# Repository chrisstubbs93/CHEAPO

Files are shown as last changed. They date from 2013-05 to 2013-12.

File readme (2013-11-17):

Flight code for $$CHEAPO flight computer

Just a simple uBlox NEO 6 GPS / RFM22B tracker

Should be uploaded to "Arduino Pro or Pro Mini (3.3v, 8MHz) w/ ATmega328"

Main tracker code is CHEAPO.INO in root directory, other code in subfolders should be treated as experimental/untested.

Current hardware CHEAPOv4 http://chris-stubbs.co.uk/wp/?p=352

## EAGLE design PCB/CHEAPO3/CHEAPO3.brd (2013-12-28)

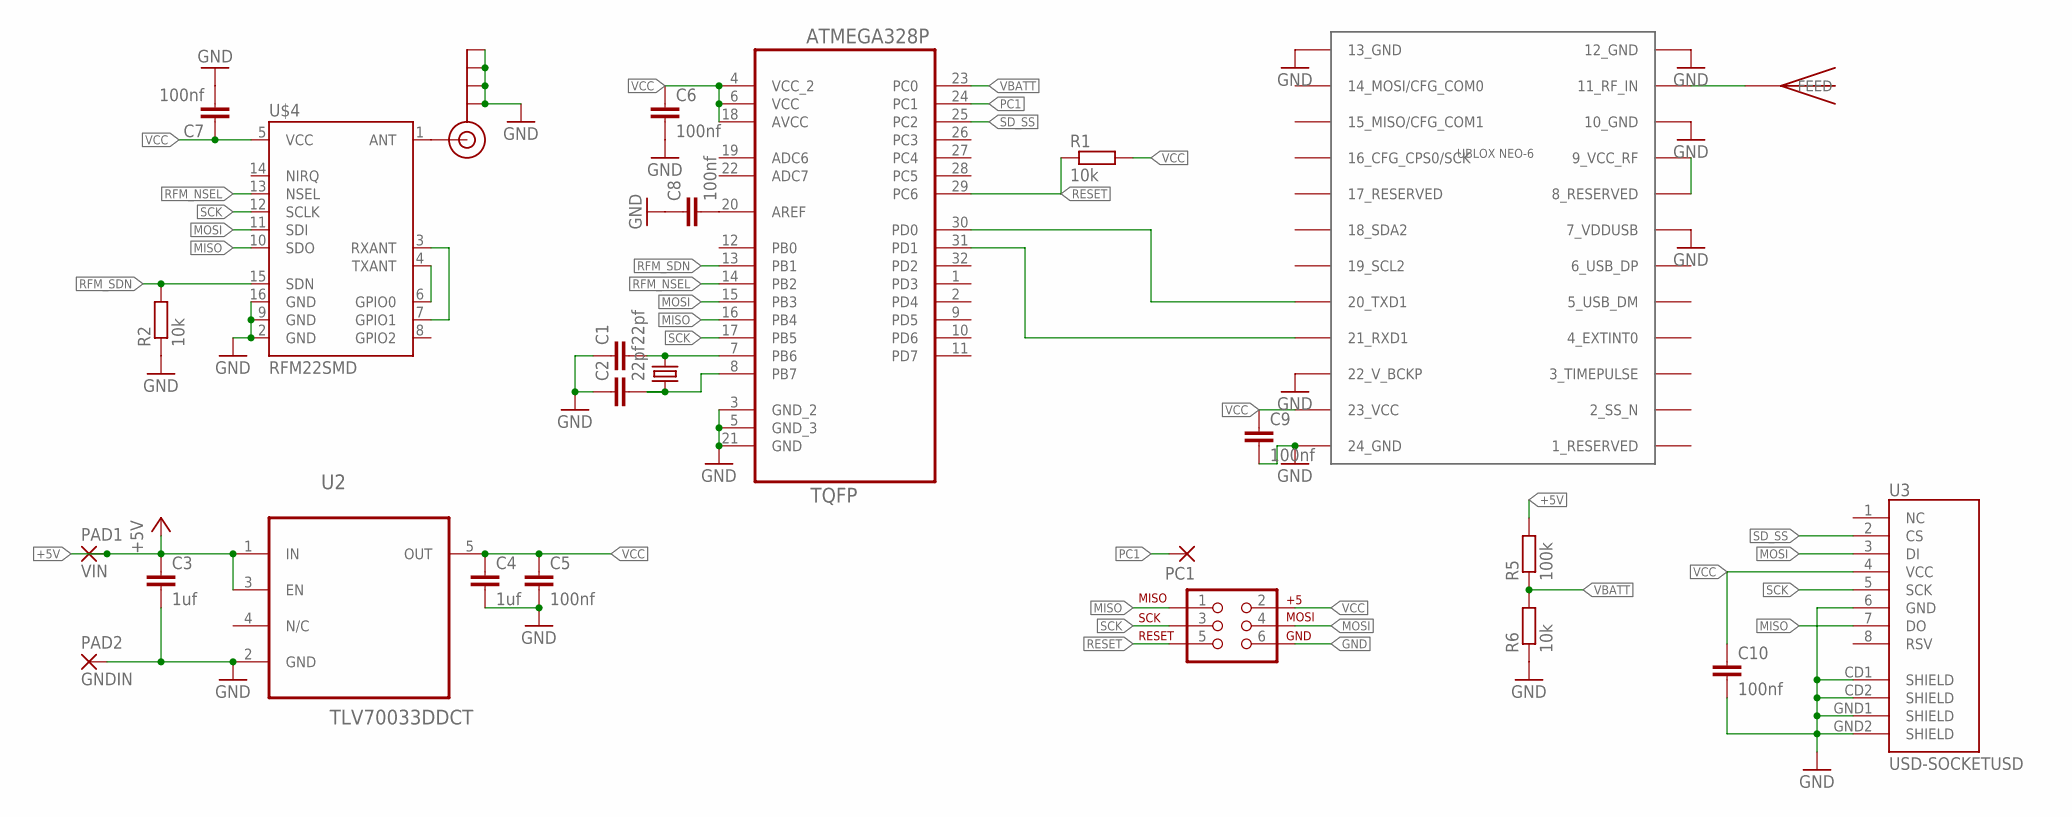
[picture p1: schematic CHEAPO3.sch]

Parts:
C1, C2: 22pf; C0603
C3, C4: 1uf; C0603
C5, C6, C7, C8, C9, C10: 100nf; C0603
J1: AVR_SPI_PRG_6PTH; 2X3
J$1: SMA_EDGE; SMA-EDGE
PAD1: VIN; SMD1,27-2,54
PAD2: GNDIN; SMD1,27-2,54
PC1: SMD2; SMD1,27-2,54
R1, R2, R6: 10k; R0603
R5: 100k; R0603
U1: ATMEGA328P-AU; QFP80P900X900X120-32N
U2: TLV70033DDCT; SOT95P280X110-5N
U3: USD-SOCKETUSD; USD-SOCKET-PP
U$1: UBLOX_NEO-6; UBLOX_NEO-6P
U$2: ABRACON_ABM3_CRYSTALABM03_HC49; ABM03_HC49
U$3: JTI_ANTENNA-1575AT43A40
U$4: RFM22SMD; RFM22-XXX-S2

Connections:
+5V: C3.1, PAD1.1, R5.2, U2.1 (IN), U2.3 (EN)
GND: C1.1, C2.1, C3.2, C4.2, C5.2, C6.2, C7.2, C8.1, C9.2, C10.2, J1.6, J$1.GND@0 (GND), J$1.GND@1 (GND), J$1.GND@2 (GND), J$1.GND@3 (GND), PAD2.1, R2.1, R6.1, U1.3 (GND_2), U1.5 (GND_3), U1.21 (GND), U2.2 (GND), U3.6 (GND), U3.CD1 (SHIELD), U3.CD2 (SHIELD), U3.GND1 (SHIELD), U3.GND2 (SHIELD), U$1.7_VDDUSB, U$1.10_GND, U$1.12_GND, U$1.13_GND, U$1.22_V_BCKP, U$1.24_GND, U$4.2 (GND), U$4.9 (GND), U$4.16 (GND)
MISO: J1.1, U1.16 (PB4), U3.7 (DO), U$4.10 (SDO)
MOSI: J1.4, U1.15 (PB3), U3.3 (DI), U$4.11 (SDI)
unnamed: C1.2, U1.7 (PB6), U$2.2
unnamed: C2.2, U1.8 (PB7), U$2.1
unnamed: U$4.4 (TXANT), U$4.6 (GPIO0)
unnamed: U$4.3 (RXANT), U$4.7 (GPIO1)
unnamed: U$1.8_RESERVED, U$1.9_VCC_RF
unnamed: U$1.11_RF_IN, U$3.FEED
unnamed: C8.2, U1.20 (AREF)
unnamed: J$1.SIG (SIGNAL), U$4.1 (ANT)
unnamed: U1.30 (PD0), U$1.20_TXD1
unnamed: U1.31 (PD1), U$1.21_RXD1
PC1: PC1.1, U1.24 (PC1)
RESET: J1.5, R1.1, U1.29 (PC6)
RFM_NSEL: U1.14 (PB2), U$4.13 (NSEL)
RFM_SDN: R2.2, U1.13 (PB1), U$4.15 (SDN)
SCK: J1.3, U1.17 (PB5), U3.5 (SCK), U$4.12 (SCLK)
SD_SS: U1.25 (PC2), U3.2 (CS)
VBATT: R5.1, R6.2, U1.23 (PC0)
VCC: C4.1, C5.1, C6.1, C7.1, C9.1, C10.1, J1.2, R1.2, U1.4 (VCC_2), U1.6 (VCC), U1.18 (AVCC), U2.5 (OUT), U3.4 (VCC), U$1.23_VCC, U$4.5 (VCC)

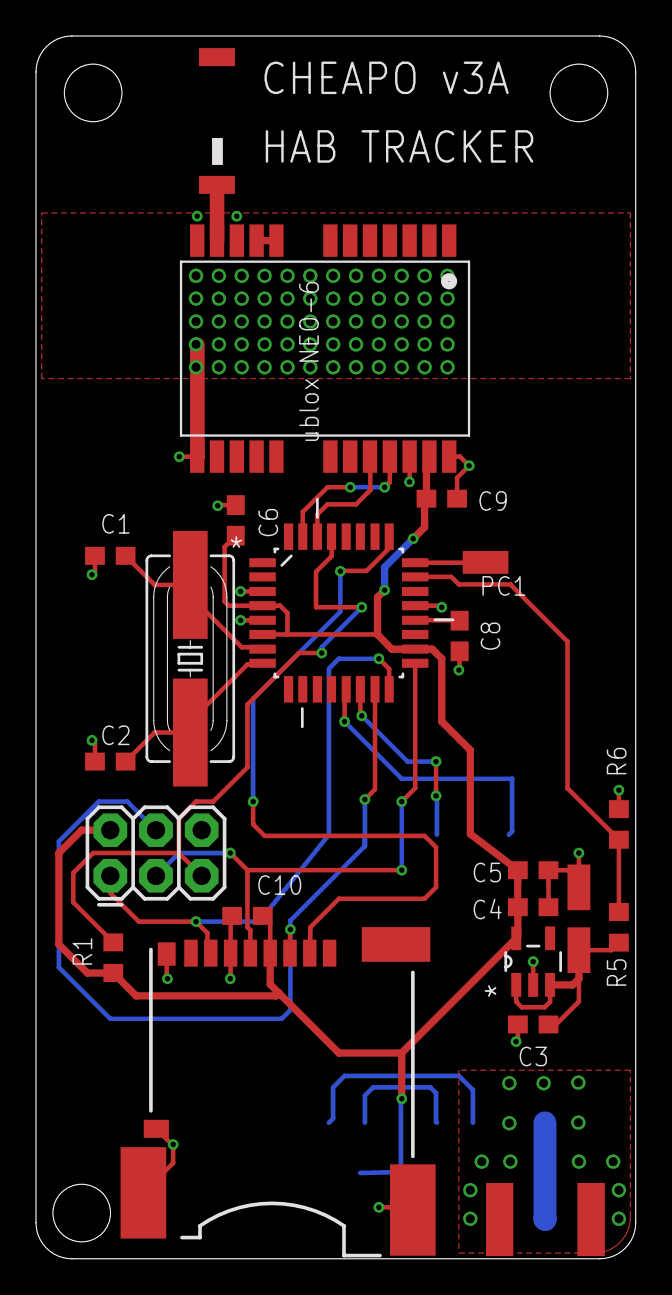
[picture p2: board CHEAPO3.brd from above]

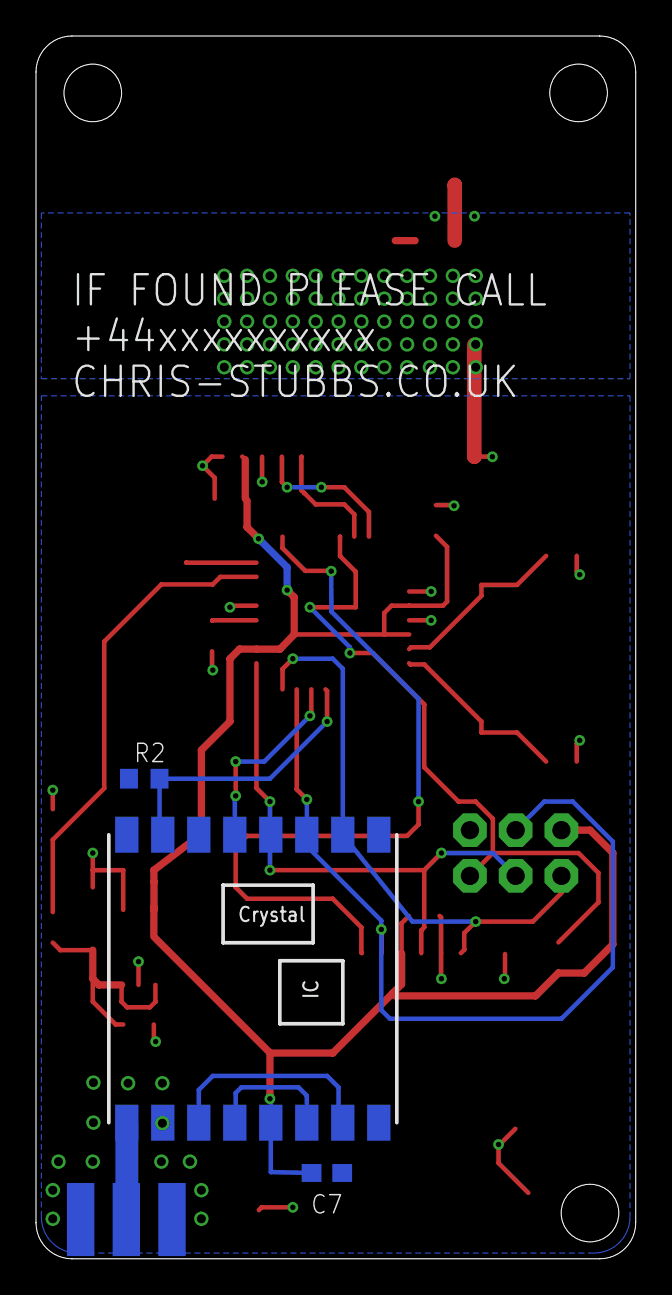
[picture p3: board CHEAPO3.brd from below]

Board: 2 copper layers, 33.3 x 67.9 mm, 26 parts (4 on the bottom side), 22 nets.

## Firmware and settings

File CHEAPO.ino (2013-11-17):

#include <avr/io.h>
#include <avr/interrupt.h>
#include <util/crc16.h>
#include <SPI.h>
#include <RFM22.h>
#include <TinyGPS.h>

TinyGPS gps;

#define ASCII 7          // 7 bit ascii
#define STOPBITS 2       // 2 stop bits
#define TXDELAY 0        // Delay between sentence TX's
#define RTTY_BAUD 50    // Baud rate for use with RFM22B Max = 600
#define RADIO_FREQUENCY 434.300 // Low side frequency for transmission
#define RADIO_POWER  0x04 //Radio power (12mW)
#define RESTART_INTERVAL  50 //Restart rfm22b every x lines
#define RFM22B_SDN 9 //RFM Power
#define RFM22B_PIN 10 //RFM SPI pin

/* Radio output power settings:
 0x02 5db (3mW)
 0x03 8db (6mW)
 0x04 11db (12mW)
 0x05 14db (25mW)
 0x06 17db (50mW)
 0x07 20db (100mW)
 */

char datastring[80]; //where the telementry string is stored
char txstring[80]; //copy of telementry string for transmission
volatile int txstatus=1;
volatile int txstringlength=0;
volatile char txc;
volatile int txi;
volatile int txj;
unsigned int count=0; //message counter
boolean setgpsmode; //has GPS been set to flight mode
boolean gps_set_sucess; //is flight mode set (bool)
boolean gps_powersave; //is powersave mode set (bool)
unsigned int alt; 
int sats = 0;
int psave;
char latstr[10] = "0"; //Lat converted to string
char lonstr[10] = "0"; //Lng converted to string
unsigned long time;
boolean radioready; //is the radio ready or down for reboot
int gpsmode; //is flight mode set? (int 1/0)
float vbatt = 0.00; //battery voltage as float
char vbatts[10] = "0"; //battery voltage as string
int xtemp = 0;
int caltemp = 0;

/*
double hlat = 51.710119;
double hlon = 0.577744;
float dist;
char diststr[5] = "0"; //dist converted to string
int R = 6371;
*/

rfm22 radio1(RFM22B_PIN);

void setup()
{
  pinMode(RFM22B_SDN, OUTPUT);    // RFM22B SDN is on ARDUINO D9
  delay(5000);// let the GPS settle down (probably not needed)
  Serial.begin(9600);
  initialise_interrupt();
  setupRadio();
}

void loop()
{
  bool newData = false;
  unsigned long chars;
  unsigned short sentences, failed;
  //sats = gps.satellites(); //reporting crazy values before fix, tinygps does not report sats anyway without 2d/3d fix

  // For 2 seconds we parse GPS data and report some key values
  for (unsigned long start = millis(); millis() - start < 2000;)
  {
    while (Serial.available())
    {
      char c = Serial.read();
      //Serial.write(c); // uncomment this line if you want to see the GPS data flowing
      if (gps.encode(c)) // Did a new valid sentence come in?
        newData = true;
    }
  }

  if(setgpsmode == true)
  {
    navmode();
  }

  if (newData)
  {

    // if we have a GPS fix. then set the ublox into flight mode. Flight mode code by Upu
    delay(250);
    setgpsmode = true;

    float flat, flon;
    unsigned long age;
    gps.f_get_position(&flat, &flon, &age);

    dtostrf(flat,9,6,latstr); // convert lat from float to string
    dtostrf(flon,9,6,lonstr); // convert lon from float to string
    alt = gps.f_altitude(); // +/- altitude in meters 
    sats = gps.satellites();

    /*
    //Haversine distance calculation. Isnt very good on the arduino due to the float precision
     float dLat = ((flat - hlat) * 71) / 4068;
     float dLon = ((flon - hlon) * 71) / 4068;
     float lat1 = ((hlat) * 71) / 4068;
     float lat2 = ((hlon) * 71) / 4068;
     float a = sin(dLat/2) * sin(dLat/2) + sin(dLon/2) * sin(dLon/2) * cos(lat1) * cos(lat2);
     float c = 2 * atan2(sqrt(a),sqrt(1-a));
     dist = R * c;
     dtostrf(dist,4,2,diststr); // convert dist from float to string
     */

    unsigned long fix_age;

    //If we have a good fix (>=5 sats), enter uBlox Power save mode
    if(sats >= 5)
    {
      if(gps_powersave == false)
      {
        uint8_t setPSM[] = { 
          0xB5, 0x62, 0x06, 0x11, 0x02, 0x00, 0x08, 0x01, 0x22, 0x92         }; // Setup for Power Save Mode (Default Cyclic 1s)
        sendUBX(setPSM, sizeof(setPSM)/sizeof(uint8_t)); // send command to ublox
        gps_powersave = true;
      }
    }


    // time in hhmmsscc, date in ddmmyy
    gps.get_datetime(0, &time, &fix_age);

    //drop cc (millis) from time to leave us with HHMMSS
    time = time / 100;

    //correct no of 0's in long, (output: 00.575950/-0.575950)
    if (lonstr[0] == ' ') {
      lonstr[0] = '0';
    }
  }
  else {
    // No new GPS data, probably no satelites or comms failure. Set the sats flag to 0 to tell habitat its an old fix
    sats = 0;
  }


  //I didnt figure out how to sprintf a boolean, so use an integer instead for the IsFlightModeSet flag.
  if(setgpsmode){
    gpsmode = 1;
  } 
  else{
    gpsmode = 0;
  }

  //is gps in power save mode?
  if(gps_powersave){
    psave = 1;
  } 
  else{
    psave = 0;
  }

  //Im not sure if this delay is needed. But leaving it in for safekeeping.
  delay(1000);
}

//Timer that fires to send each RTTY bit. From Upu
ISR(TIMER1_COMPA_vect)
{
  if (radioready == true) //is the radio up and running? if not its down for reboot
  {
    switch(txstatus) {
    case 0: // This is the optional delay between transmissions.
      txj++;
      if(txj>(TXDELAY*RTTY_BAUD)) {
        txj=0;
        txstatus=1;
      }
      break;
    case 1: // Initialise transmission, take a copy of the string so it doesn't change mid transmission.
      vbatt = ((3.2 / 1024)* analogRead(A0) * 11.2); // ((vcc / maxADC)* adcreading * voltageDividerRatio)
      dtostrf(vbatt,3,2,vbatts); // convert lat from float to string

      radio1.write(0x0F, 0x00); // RF22_REG_0F_ADC_CONFIGURATION 0x0f  :  RF22_ADCSEL_INTERNAL_TEMPERATURE_SENSOR 0x00 Temprtature sensor, oo, yes plz
      radio1.write(0x12, 0x00); // set temp range (-64 - +64 degC)
      radio1.write(0x12, 0x20); // set ENTSOFF (wtf is that?)
      radio1.write(0x0F, 0x80); // RF22_REG_0F_ADC_CONFIGURATION 0x0f  :  RF22_ADCSTART 0x80  After reading the manual you must set this self clearing bit to get the ADC to take a reading
      delayMicroseconds(400); //wait > 350 us for ADC converstion
      xtemp = radio1.read(0x11); //Register 11h. ADC Value. What units this returns in I have no idea. Degrees bannana? - Oh its an ADC value, so probably 0-255
      caltemp = xtemp * 0.5 - 64 - 7;


      sprintf(datastring,"$$$$CHEAPO,%i,%06lu,%s,%s,%i,%i,%i%i,%s,%i",count,time,latstr,lonstr,alt,sats,gpsmode,psave,vbatts,caltemp); //put together all var into one string //now runs at end of loop()
      crccat(datastring + 4); //add checksum (lunars code)
      count = count + 1;
      strcpy(txstring,datastring);
      txstringlength=strlen(txstring);
      txstatus=2;
      txj=0;
      break;
    case 2: // Grab a char and lets go transmit it.
      if ( txj < txstringlength)
      {
        txc = txstring[txj];
        txj++;
        txstatus=3;
        rtty_txbit (0); // Start Bit;
        txi=0;
      }
      else
      {
        txstatus=0; // Should be finished
        txj=0;

        //power cycle
        if(count % RESTART_INTERVAL == 0)
        {
          powercycle();
        }


      }
      break;
    case 3:
      if(txi<ASCII)
      {
        txi++;
        if (txc & 1) rtty_txbit(1);
        else rtty_txbit(0);  
        txc = txc >> 1;
        break;
      }
      else
      {
        rtty_txbit (1); // Stop Bit
        txstatus=4;
        txi=0;
        break;
      }
    case 4:
      if(STOPBITS==2)
      {
        rtty_txbit (1); // Stop Bit
        txstatus=2;
        break;
      }
      else
      {
        txstatus=2;
        break;
      }

    }
  } 
  else
  {
    // do nothing, radio is resetting.
  }
}

//Switch the radios frequency Low/High depending on the current bit.
void rtty_txbit (int bit)
{
  if (bit)
  {
    radio1.write(0x73,0x03); // High
  }
  else
  {
    radio1.write(0x73,0x00); // Low
  }
}

//Turn on and set up the RFM22B radio transmitter.
void setupRadio(){
  digitalWrite(RFM22B_SDN, LOW);
  delay(1000);
  rfm22::initSPI();
  radio1.init();
  radio1.write(0x71, 0x00); // unmodulated carrier
  //This sets up the GPIOs to automatically switch the antenna depending on Tx or Rx state, only needs to be done at start up
  radio1.write(0x0b,0x12);
  radio1.write(0x0c,0x15);
  radio1.setFrequency(RADIO_FREQUENCY);
  radio1.write(0x6D, RADIO_POWER);
  radio1.write(0x07, 0x08);
  delay(500);
  radioready = true;
}


//Start the timer interrupt to send RTTY bits.
void initialise_interrupt()
{
  // initialize Timer1
  cli();          // disable global interrupts
  TCCR1A = 0;     // set entire TCCR1A register to 0
  TCCR1B = 0;     // same for TCCR1B
  OCR1A = F_CPU / 1024 / RTTY_BAUD - 1;  // set compare match register to desired timer count:
  TCCR1B |= (1 << WGM12);   // turn on CTC mode:
  // Set CS10 and CS12 bits for:
  TCCR1B |= (1 << CS10);
  TCCR1B |= (1 << CS12);
  // enable timer compare interrupt:
  TIMSK1 |= (1 << OCIE1A);
  sei();          // enable global interrupts
}


// Send a command (byte array of UBX protocol) to the GPS
void sendUBX(uint8_t *MSG, uint8_t len) {
  for(int i=0; i<len; i++) {
    Serial.write(MSG[i]);
    // Serial.print(MSG[i], HEX);
  }
  Serial.println();
}



// Calculate expected UBX ACK packet and parse UBX response from GPS
boolean getUBX_ACK(uint8_t *MSG) {
  uint8_t b;
  uint8_t ackByteID = 0;
  uint8_t ackPacket[10];
  unsigned long startTime = millis();
  //Serial.print(" * Reading ACK response: ");

  // Construct the expected ACK packet    
  ackPacket[0] = 0xB5;	// header
  ackPacket[1] = 0x62;	// header
  ackPacket[2] = 0x05;	// class
  ackPacket[3] = 0x01;	// id
  ackPacket[4] = 0x02;	// length
  ackPacket[5] = 0x00;
  ackPacket[6] = MSG[2];	// ACK class
  ackPacket[7] = MSG[3];	// ACK id
  ackPacket[8] = 0;		// CK_A
  ackPacket[9] = 0;		// CK_B

  // Calculate the checksums
  for (uint8_t i=2; i<8; i++) {
    ackPacket[8] = ackPacket[8] + ackPacket[i];
    ackPacket[9] = ackPacket[9] + ackPacket[8];
  }

  while (1) {

    // Test for success
    if (ackByteID > 9) {
      // All packets in order!
      // Serial.println(" (SUCCESS!)");
      return true;
    }

    // Timeout if no valid response in 3 seconds, if this keeps happeneing check GPS TX/RX and data voltage levels.
    if (millis() - startTime > 3000) { 
      //Serial.println(" (FAILED!)");
      return false;
    }

    // Make sure data is available to read
    if (Serial.available()) {
      b = Serial.read();

      // Check that bytes arrive in sequence as per expected ACK packet
      if (b == ackPacket[ackByteID]) { 
        ackByteID++;
        // Serial.print(b, HEX);
      } 
      else {
        ackByteID = 0;	// Reset and look again, invalid order
      }

    }
  }
}

// CRC16 Checksum from Lunar_Lander
uint16_t crccat(char *msg)
{
  uint16_t x;
  for(x = 0xFFFF; *msg; msg++)
    x = _crc_xmodem_update(x, *msg);
  snprintf(msg, 8, "*%04X\n", x);
  return(x);
}


//Reboot radio
void powercycle()
{
  radioready = false; //radio down for reboot

  //The delay dosent seem to do anything, so run it loads of times. One day I will look into this.
  for (int i = 0; i < 50; i++)  {
    digitalWrite(RFM22B_SDN, HIGH); //power down radio
    delay(500); //pause 500ms   
  }

  delay(500); //Attempt to pause 500ms. Not that delay() does anything here.
  setupRadio(); //turn on radio and set up
}

void navmode()
{
  uint8_t setNav[] = {
    0xB5, 0x62, 0x06, 0x24, 0x24, 0x00, 0xFF, 0xFF, 0x06, 0x03, 0x00, 0x00, 0x00, 0x00, 0x10, 0x27, 0x00, 0x00, 0x05, 0x00, 0xFA, 0x00, 0xFA, 0x00, 0x64, 0x00, 0x2C, 0x01, 0x00, 0x00, 0x00, 0x00, 0x00, 0x00, 0x00, 0x00, 0x00, 0x00, 0x00, 0x00, 0x00, 0x00, 0x16, 0xDC                                };
  while(!gps_set_sucess)
  {
    sendUBX(setNav, sizeof(setNav)/sizeof(uint8_t));
    gps_set_sucess=getUBX_ACK(setNav);
    delay(1000);
  }
  gps_set_sucess=0;
  setgpsmode = true;
}

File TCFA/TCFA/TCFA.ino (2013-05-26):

/*
 Interrupt Driven RTTY TX Demo
   
 Transmits data via RTTY with an interupt driven subroutine.
   
 By Anthony Stirk M0UPU  
 
 Edited by Chris Stubbs M6EDF (chris-stubbs.co.uk) for experimental purposes (temperature compensated frequency adjustment code)
 
 Temperature reference from http://www.airspayce.com/mikem/arduino/RF22/
   
 October 2012 Version 5
   
 Thanks and credits :
 Evolved from Rob Harrison's RTTY Code.
 Compare match register calculation by Phil Heron.
 Thanks to : http://www.engblaze.com/microcontroller-tutorial-avr-and-arduino-timer-interrupts/
 RFM22B Code from James Coxon http://ukhas.org.uk/guides:rfm22b  
 Suggestion to use Frequency Shift Registers by Dave Akerman (Daveake)/Richard Cresswell (Navrac)
   
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
 See <http://www.gnu.org/licenses/>.
 */
#include <avr/io.h>
#include <avr/interrupt.h>
#include <util/crc16.h>
#include <SPI.h>
#include <RFM22.h>
 
#define ASCII 7          // ASCII 7 or 8
#define STOPBITS 2       // Either 1 or 2
#define TXDELAY 0        // Delay between sentence TX's
#define RTTY_BAUD 100    // Baud rate for use with RFM22B Max = 600
//#define centerfreq 434.65025
 float target = 434.650;
 float calibratedial = 434.650;
 float centerfreq = (target + (target - calibratedial));
 
#define RFM22B_SDN 9
#define RFM22B_PIN 10
 
char datastring[80];
char txstring[80];
volatile int txstatus=1;
volatile int txstringlength=0;
volatile char txc;
volatile int txi;
volatile int txj;
unsigned int count=0;
int mid = 0x80;
 
 
rfm22 radio1(RFM22B_PIN);
 
void setup()
{
  initialise_interrupt();
  setupRadio();
  Serial.begin(9600);
}
 
void loop()
{
  radio1.write(0x0F, 0x00); // RF22_REG_0F_ADC_CONFIGURATION 0x0f  :  RF22_ADCSEL_INTERNAL_TEMPERATURE_SENSOR 0x00 Temprtature sensor, oo, yes plz
  radio1.write(0x12, 0x00); // set temp range (-64 - +64 degC)
  radio1.write(0x12, 0x20); // set ENTSOFF (wtf is that?)
  radio1.write(0x0F, 0x80); // RF22_REG_0F_ADC_CONFIGURATION 0x0f  :  RF22_ADCSTART 0x80 Fuck knows what this does, maybe you call it start the ADC? After reading the manual you must set this self clearing bit to get the ADC to take a reading
  delayMicroseconds(360); //wait > 350 us for ADC converstion
  int xtemp = radio1.read(0x11); //Register 11h. ADC Value. What units this returns in I have no idea. Degrees bannana? - Oh its an ADC value, so probably 0-255
  //int xtal = radio1.read(0x09);
  int caltemp = xtemp * 0.5 - 64 - 3;
  
  int hzshift = (xtemp - 172) * 5;
  float mhzshift = hzshift * 0.00001;
  
  sprintf(datastring,"$$c,%i,%i", xtemp,hzshift); // Puts the text in the datastring
 // unsigned int CHECKSUM = gps_CRC16_checksum(datastring);  // Calculates the checksum for this datastring
 // char checksum_str[6];
  //sprintf(checksum_str, "*%04X", CHECKSUM);
 // strcat(datastring,checksum_str);
  strcat(datastring,"\n");
  //radio1.write(0x09, mid); //Chaning the crystal loading cap settings was a shitty idea
  //mid += 1;
  Serial.println(datastring);
  
  
  
  //centerfreq += 0.0001; // 150hz
  radio1.setFrequency(centerfreq + mhzshift);
  
  
  delay(1000);
  count++;
}
 
ISR(TIMER1_COMPA_vect)
{
  switch(txstatus) {
  case 0: // This is the optional delay between transmissions.
    txj++;
    if(txj>(TXDELAY*RTTY_BAUD)) {  
      txj=0;
      txstatus=1;
    }
    break;
  case 1: // Initialise transmission, take a copy of the string so it doesn't change mid transmission.  
    strcpy(txstring,datastring);
    txstringlength=strlen(txstring);
    txstatus=2;
    txj=0;
    break;
  case 2: // Grab a char and lets go transmit it.  
    if ( txj < txstringlength)
    {
      txc = txstring[txj];
      txj++;
      txstatus=3;
      rtty_txbit (0); // Start Bit;
      txi=0;
    }
    else
    {
      txstatus=0; // Should be finished
      txj=0;
    }
    break;
  case 3:
    if(txi<ASCII)
    {
      txi++;
      if (txc & 1) rtty_txbit(1);  
      else rtty_txbit(0);    
      txc = txc >> 1;
      break;
    }
    else
    {
      rtty_txbit (1); // Stop Bit
      txstatus=4;
      txi=0;
      break;
    }  
  case 4:
    if(STOPBITS==2)
    {
      rtty_txbit (1); // Stop Bit
      txstatus=2;
      break;
    }
    else
    {
      txstatus=2;
      break;
    }
 
  }
}
 
void rtty_txbit (int bit)
{
  if (bit)
  {
    radio1.write(0x73,mid + 3); // High 0x03
  }
  else
  {
    radio1.write(0x73,mid); // Low
  }
}
 
void setupRadio(){
  pinMode(RFM22B_SDN, OUTPUT);    // RFM22B SDN is on ARDUINO A3
  digitalWrite(RFM22B_SDN, LOW);
  delay(1000);
  rfm22::initSPI();
  radio1.init();
  radio1.write(0x71, 0x00); // unmodulated carrier
  //This sets up the GPIOs to automatically switch the antenna depending on Tx or Rx state, only needs to be done at start up
  radio1.write(0x0b,0x12);
  radio1.write(0x0c,0x15);
  radio1.setFrequency(centerfreq);
  radio1.write(0x6D, 0x04);// turn tx low power 11db
  radio1.write(0x07, 0x08);
  
  delay(500);
}
 
uint16_t gps_CRC16_checksum (char *string)
{
  size_t i;
  uint16_t crc;
  uint8_t c;
 
  crc = 0xFFFF;
 
  // Calculate checksum ignoring the first two $s
  for (i = 5; i < strlen(string); i++)
  {
    c = string[i];
    crc = _crc_xmodem_update (crc, c);
  }
 
  return crc;
}    
void initialise_interrupt()  
{
  // initialize Timer1
  cli();          // disable global interrupts
  TCCR1A = 0;     // set entire TCCR1A register to 0
  TCCR1B = 0;     // same for TCCR1B
  OCR1A = F_CPU / 1024 / RTTY_BAUD - 1;  // set compare match register to desired timer count:
  TCCR1B |= (1 << WGM12);   // turn on CTC mode:
  // Set CS10 and CS12 bits for:
  TCCR1B |= (1 << CS10);
  TCCR1B |= (1 << CS12);
  // enable timer compare interrupt:
  TIMSK1 |= (1 << OCIE1A);
  sei();          // enable global interrupts
}

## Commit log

2013-03-24 CHEAPO code added, NOT FLIGHT READY
    All working. probably could fly. need to add RFM22B power cycling.
2013-03-24 Added power cycling code & optimised. needs testing
2013-03-27 Sats = 0 with no fix & comments
    Sats now = 0 when there is no new GPS data. Added a few comments.
    restart interval and radio power are now defined at the top. Power
    cycling is tested and seems to work, but code is pretty bad.
    [CHEAPO.ino]
2013-04-21 Fixed padding on time & unsigned int altitude
    The code worked fine in flight apart from dropping the first 0 in times
    before 10AM eg 064500 was printed as 64500. That should now be fixed.
    Altitude has also been changed to an unsigned int to allow altitudes of
    up to 65535m
    [CHEAPO.ino]
2013-06-04 Added temp sensing
    Temp sensing calibrated for CHEAPO v3A1
2013-08-23 Navmode settings changed
    Navmode is set every second in case of reset >12k
    [CHEAPO.ino]
2013-11-11 GPS Sats only set after lock
    Code tidied
    Sats is only set after lock now as tinygps will only report back sats if
    it has a 2d/3d fix anyway and we were getting crazy values.
    [CHEAPO.ino]
2013-12-28 Added PCB eagle files
    [CHEAPO3.brd, CHEAPO3.sch, CHEAPO4.brd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]
2013-12-28 Added eagle PCB files
    [CHEAPO3.brd, CHEAPO4.brd]

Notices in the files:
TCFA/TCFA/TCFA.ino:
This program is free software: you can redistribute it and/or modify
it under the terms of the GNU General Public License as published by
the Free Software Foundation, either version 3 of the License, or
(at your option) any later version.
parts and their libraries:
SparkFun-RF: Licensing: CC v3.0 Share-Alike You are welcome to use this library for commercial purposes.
